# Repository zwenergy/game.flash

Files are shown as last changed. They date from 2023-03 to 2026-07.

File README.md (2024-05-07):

# game.flash
A Flash cartridge for the Tiger game.com handheld.

## Cartridge PCB
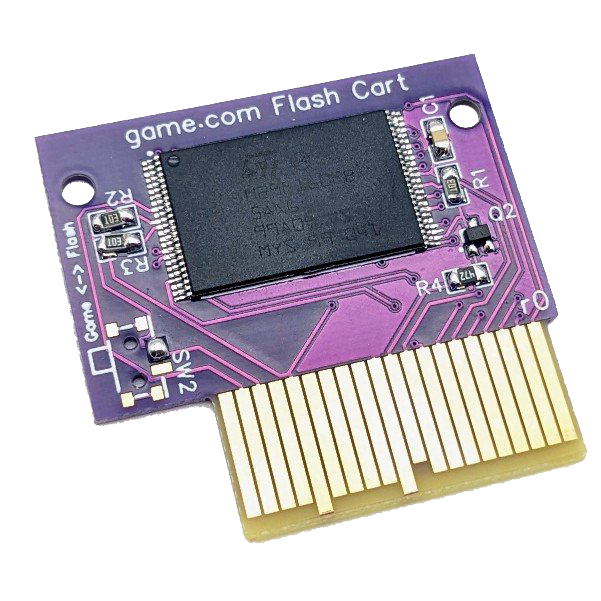
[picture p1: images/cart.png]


### BOM
| **Reference** | **Part** | **Link** |
|---|---|---|
|U1 | M29F160FB5AN6F2 2 MB Flash | [Digikey](https://www.digikey.de/en/products/detail/alliance-memory-inc/M29F160FB5AN6F2/12180105)|
|R1, R2, R3 | 10 kOhm Resistor (0805) | [LCSC](https://www.lcsc.com/product-detail/Chip-Resistor-Surface-Mount_UNI-ROYAL-Uniroyal-Elec-0805W8F1002T5E_C17414.html) |
|R4 | 4.7 kOhm Resistor (0805) | [LCSC](https://www.lcsc.com/product-detail/Chip-Resistor-Surface-Mount_UNI-ROYAL-Uniroyal-Elec-0805W8F4701T5E_C17673.html)
|C1 | 100 nF Capacitor (0805) | [LCSC](https://www.lcsc.com/product-detail/Multilayer-Ceramic-Capacitors-MLCC-SMD-SMT_YAGEO-CC0805KRX7R9BB104_C49678.html)
|Q2 | NPN Transistor (SOT-323-3) | [LCSC](https://www.lcsc.com/product-detail/Bipolar-Transistors-BJT_PANJIT-International-MMBT3904W_R1_00001_C142339.html)

The switch SW2 is not actually needed.
Instead, just connect the two pads as shown in the picture.

### Ordering Cartridge PCB
Order the cartridge PCB with ENIG/gold plated, "gold fingers" and chamfered edges.
Since, e.g., JLCPCB needs a minimum size for those features, you can find a panelized version which should fulfill those requirements.

A PCB thickness of 1.0 mm or 1.2 mm should work (1.0 mm works for me well, 1.2 mm is also successfully tested by somebody else).
Original game.com cartridge PCB seem to have a thickness of 1.0 mm or slightly above.
**When ordering thickness of 1.0 mm, you most likely have to slightly adjust the cart edge connector of the flasher PCB (e.g., carefully bend all pins slightly a bit more towards the center to put more pressure on the contacts), as otherwise the PCB is too loose and does not make properly contact (though works without problems for me on the game.com device).**

### Cartridge Case
An initial version of a 3D printable case is inside the case folder.
There are 2 "back part" versions.
One which has a "lip" like the original case (harder to print with an FDM printer), and one which has "flap" which more FDM printer-friendly.
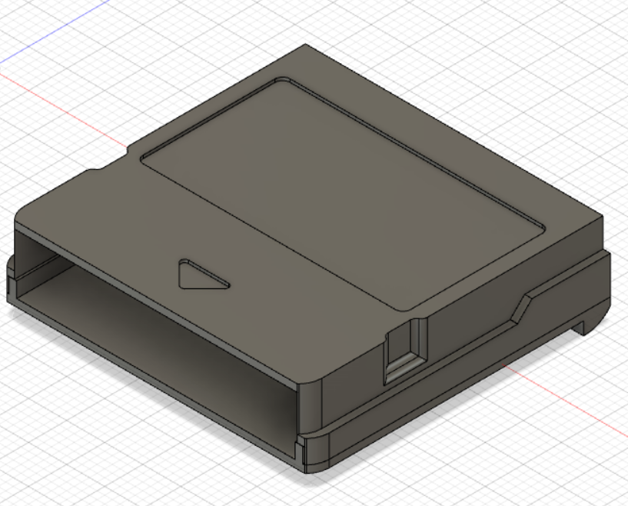
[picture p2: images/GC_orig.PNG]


A regular game.com cartridge case *should* work, although the cases seem to have quite some tolerance.
This means that some fit for me, some are too tight.

## Flasher PCB
The Flash chip on the cartridge can be re-flashed using an Arduino Mega and a "flasher shield".
**Make sure to insert the cartridge PCB's side with the Flash chip oriented towards the marked "chip-side" on the flasher PCB.**

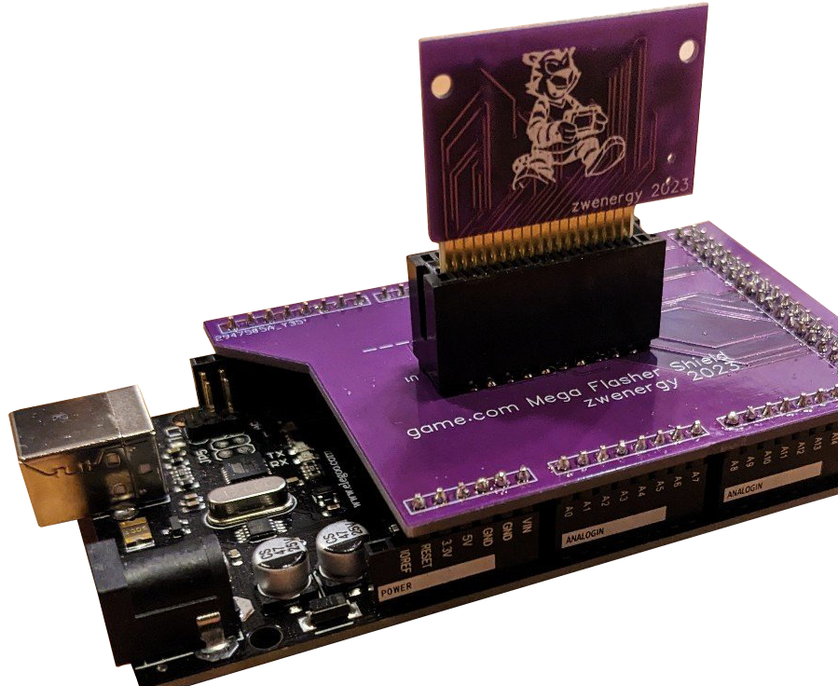
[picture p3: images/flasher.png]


### BOM
| **Reference** | **Part** | **Link** |
|---|---|---|
|U1 | RBB20DHHN Edge Connector | [Digikey](https://www.digikey.de/en/products/detail/sullins-connector-solutions/RBB20DHHN/927330)

## Flashing Software
Can be found under the code directory.
As a first step, program the Arduino Mega using the given .ino file and the Arduino IDE.
You don't need to redo this step anymore.

### Flashing script
A ROM file is flashed onto the cartridge by using the Python script ```flash.py```.
Make sure that you have Python installed. You also need the PySerial package.

The flash script can be used as follows:
```
flash.py ROMFILE COMPORT [MIRROR]
```

The parameter ```MIRROR``` is optional an can be either ```TRUE``` or ```FALSE``` (by default it is turned off).

Enabling ```MIRROR``` can be used to make "small" ROMs work (smaller than 2 MB). 
This is due to the that those smaller cartridges do not have the uppper address lines connected.
Hence the content "repeats" from the view of the handheld and it seems that it relies on this. 
As a "fix", I added the ```MIRROR``` option to the flashing script which repeats the content of the ROM along the 2 MB.
E.g., Lights Out only has the lower 15 address lines connected (from a total of 21 address lines). 
That means adress 0x0 will be the same as 0x8000, or 0x10000, etc.
My current guess is that the header is always checked at 0x40000, but just padding the header to that address is not enough.

Flashing a full 2 MB ROM currently takes around 15 minutes.

## Disclaimer
**Use the files and/or schematics to build your own board at your own risk**.
This board works fine for me, but it's a simple hobby project, so there is no liability for errors in the schematics and/or board files.
**Use at your own risk**.

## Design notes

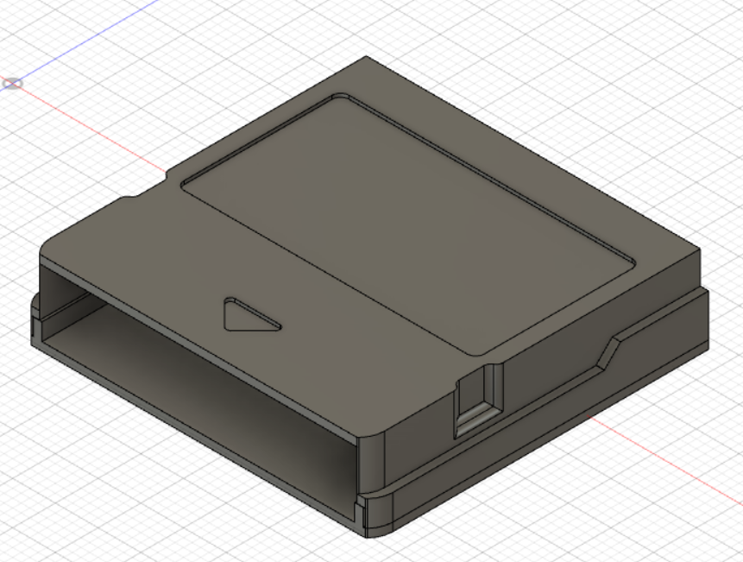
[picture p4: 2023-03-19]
images/GC_flap.PNG

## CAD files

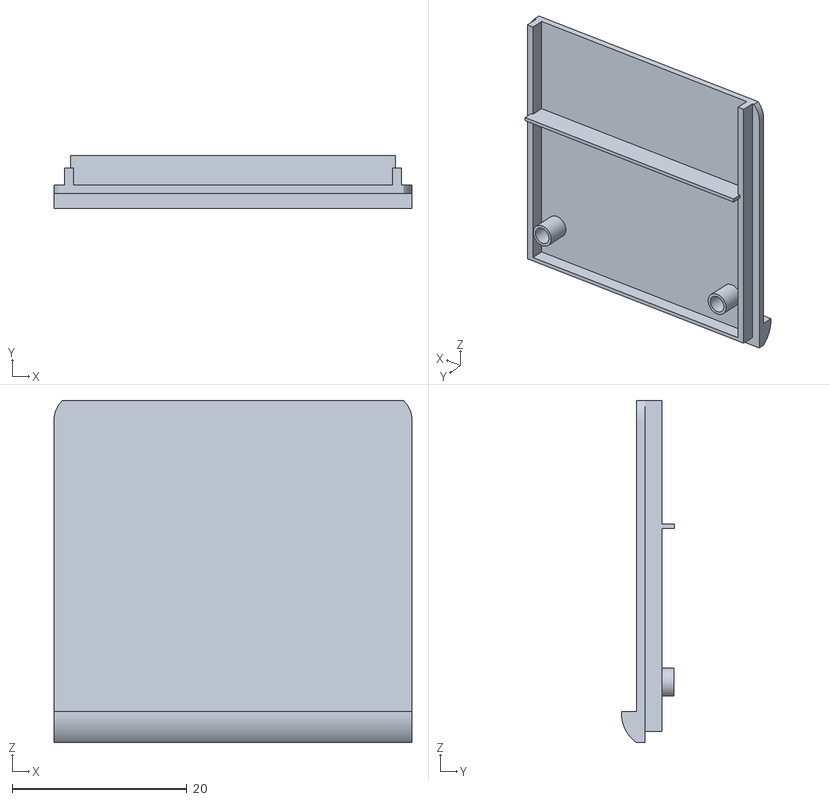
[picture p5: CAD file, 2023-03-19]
case/back_orig.stl
41.0 x 6.08 x 39.2

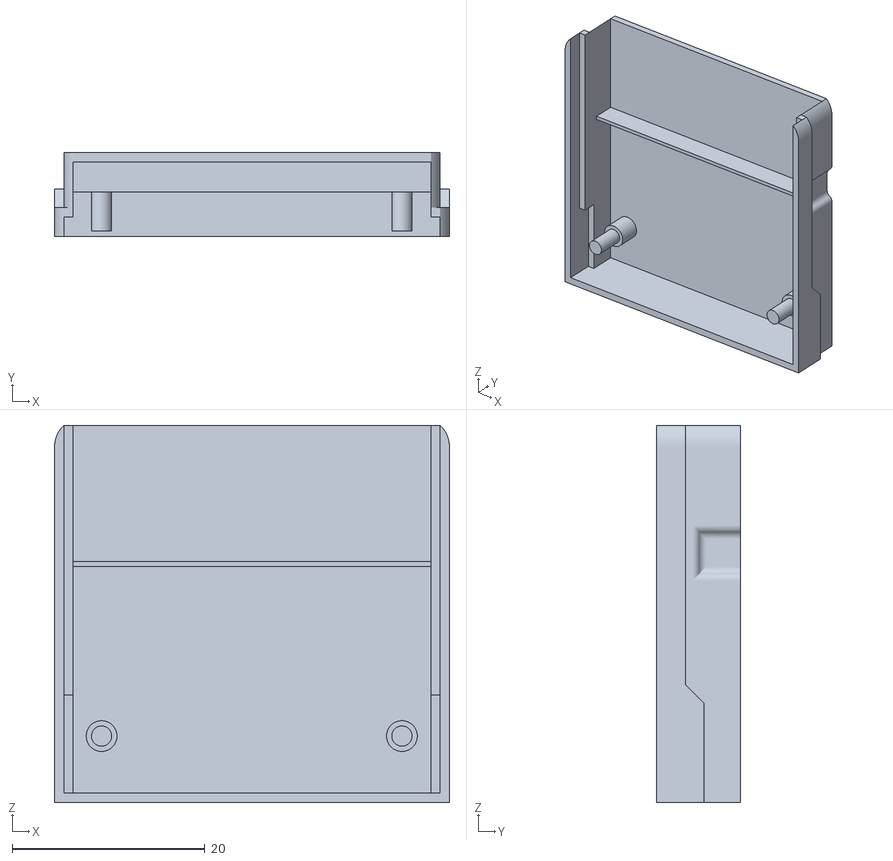
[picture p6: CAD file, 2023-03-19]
case/top.stl
41.0 x 8.73 x 39.2

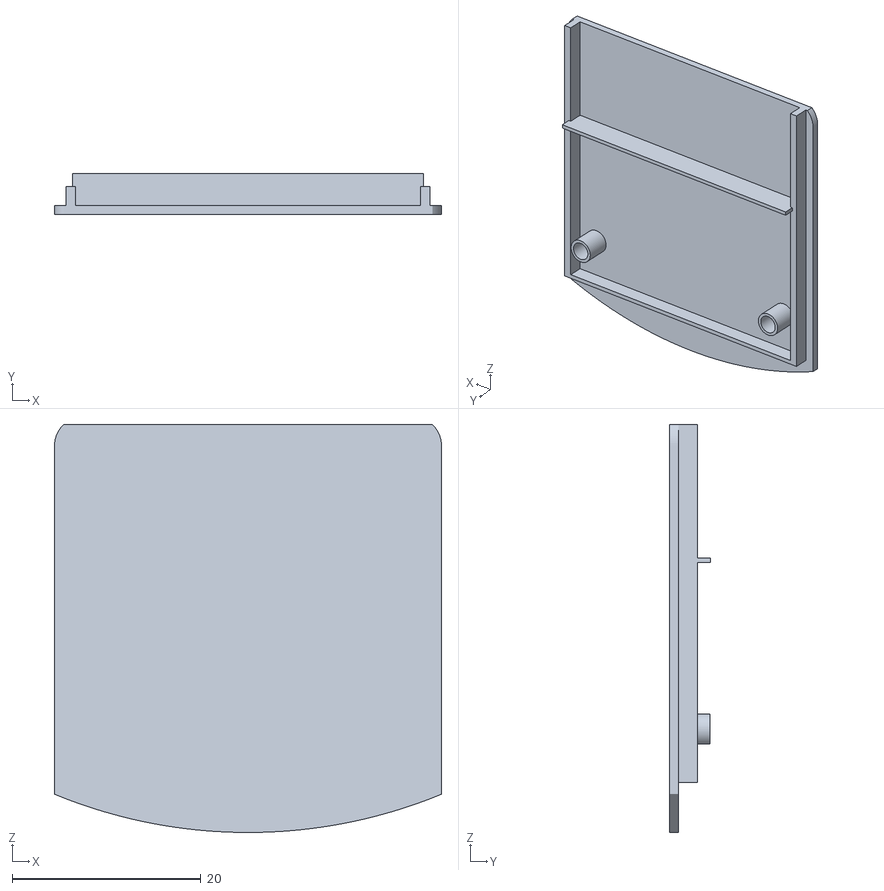
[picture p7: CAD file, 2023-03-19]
case/back_flap.stl
41.0 x 4.38 x 43.3

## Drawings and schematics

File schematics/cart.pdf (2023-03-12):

# A7 18 A6 19 A5 20 A4 21 A3 22 A2 23 A1 24 A0 25

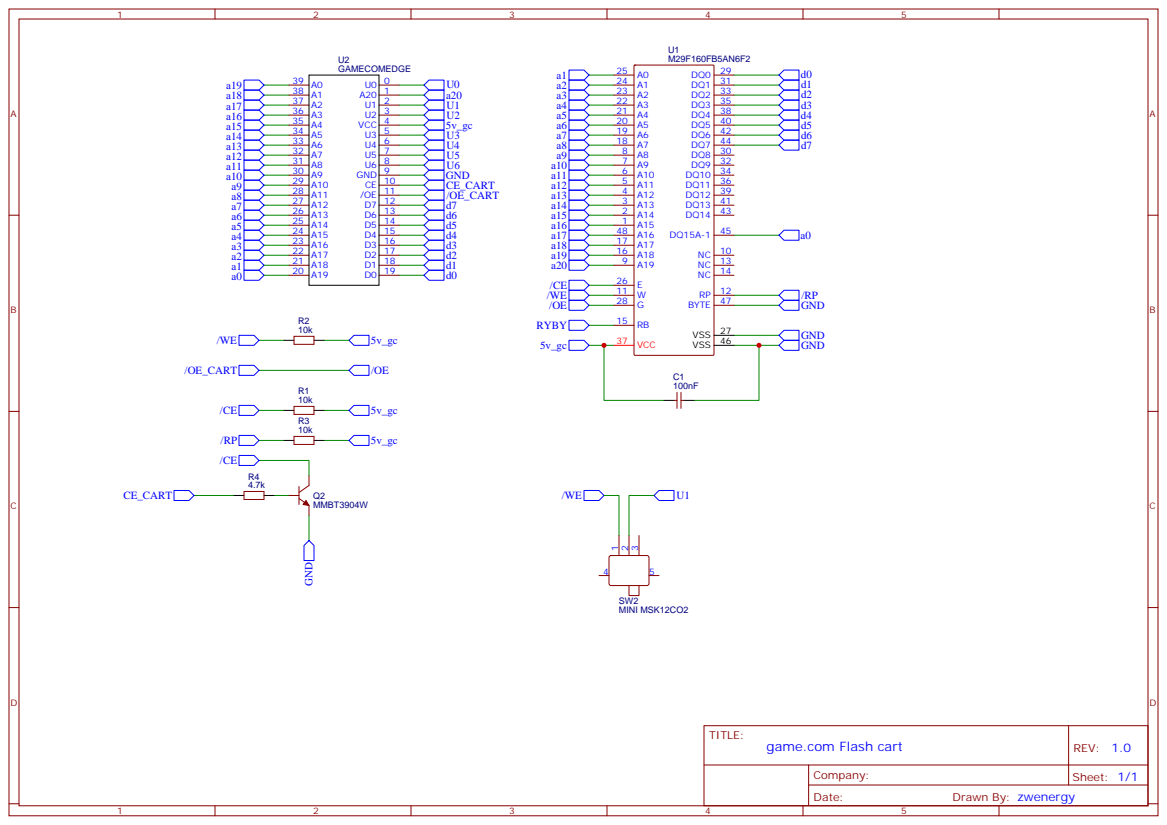
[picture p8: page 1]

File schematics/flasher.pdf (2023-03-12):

A

A

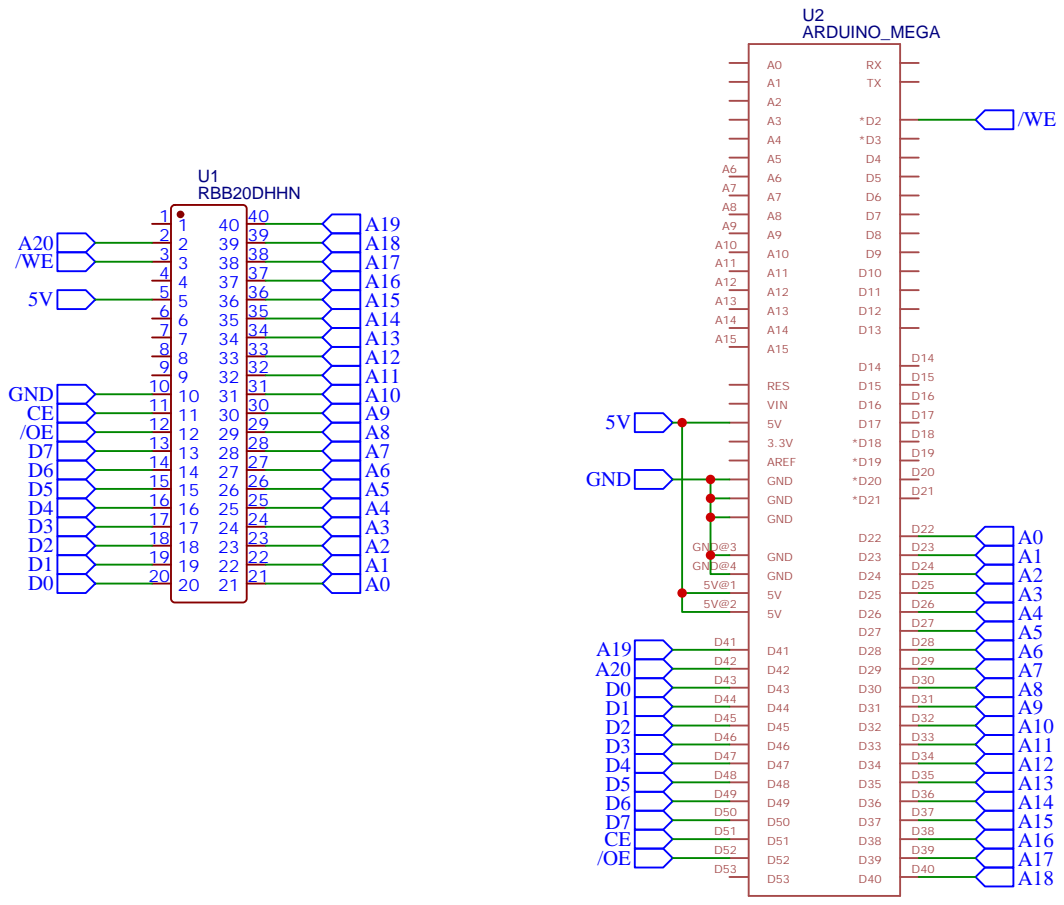
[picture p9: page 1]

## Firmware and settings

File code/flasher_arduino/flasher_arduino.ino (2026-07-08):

// Types (assuming you have these typedef'd elsewhere, standardizing for safety)
typedef uint32_t u32;
typedef uint8_t  u8;

// Pin definitions kept for reference, but physical manipulation 
// is now handled directly via hardware PORT registers.
#define A0 22
#define A1 23
#define A2 24
#define A3 25
#define A4 26
#define A5 27
#define A6 28
#define A7 29
#define A8 30
#define A9 31
#define A10 32
#define A11 33
#define A12 34
#define A13 35
#define A14 36
#define A15 37
#define A16 38
#define A17 39
#define A18 40
#define A19 41
#define A20 42

#define D0 43
#define D1 44
#define D2 45
#define D3 46
#define D4 47
#define D5 48
#define D6 49
#define D7 50

#define nWE 2  // PE4
#define nRP 3  // PE5
#define nRB 4  // PG5
#define CE 51  // PB2
#define nOE 52 // PB1

// Fast Control Pin Macros
#define nWE_HIGH (PORTE |= (1 << 4))
#define nWE_LOW  (PORTE &= ~(1 << 4))
#define nRP_HIGH (PORTE |= (1 << 5))
#define nRP_LOW  (PORTE &= ~(1 << 5))
#define CE_HIGH  (PORTB |= (1 << 2))
#define CE_LOW   (PORTB &= ~(1 << 2))
#define nOE_HIGH (PORTB |= (1 << 1))
#define nOE_LOW  (PORTB &= ~(1 << 1))

// Debug offset for dumping
#define OFFSET 262144
//#define OFFSET 0
#define MAXADDR 2097152

// Baud rate.
#define BAUD (250000)

// Wait time for chip erase. This is typically 25 seconds according to the data sheet, yet 
// at max. 120 seconds. If flashing is not done correctly, trying increasing this time value.
#define ERASE_WAIT_MS 30000

// NOP definitions for timing predictability
#define NOP1 asm volatile( "nop\n" )
#define NOP2 NOP1; NOP1
#define WAITSEQ NOP2

#define RXBYTES 32

void setDatPinsInput() {
  // D0-D6 map to PL6-PL0. D7 maps to PB3.
  DDRL &= 0b10000000; // Set PL0-PL6 to INPUT (leaves PL7 / A20 alone)
  DDRB &= ~(1 << 3);  // Set PB3 to INPUT
}

void setDatPinsOutput() {
  // D0-D6 map to PL6-PL0. D7 maps to PB3.
  DDRL |= 0b01111111; // Set PL0-PL6 to OUTPUT (leaves PL7 / A20 alone)
  DDRB |= (1 << 3);   // Set PB3 to OUTPUT
}

void setup() {
  Serial.begin( BAUD );
  
  // Set Address Pins to OUTPUT directly via Data Direction Registers (DDR)
  DDRA = 0xFF;         // A0-A7 (Pins 22-29) -> PA0-PA7
  DDRC = 0xFF;         // A8-A15 (Pins 30-37) -> PC7-PC0
  DDRD |= (1 << 7);    // A16 (Pin 38) -> PD7
  DDRG |= 0b00000111;  // A17-A19 (Pins 39-41) -> PG2, PG1, PG0
  DDRL |= (1 << 7);    // A20 (Pin 42) -> PL7

  // Data pins default to input
  setDatPinsInput();

  // Control pins direction setup
  DDRE |= (1 << 4);    // nWE (Pin 2, PE4) OUTPUT
  DDRE |= (1 << 5);    // nRP (Pin 3, PE5) OUTPUT
  DDRG &= ~(1 << 5);   // nRB (Pin 4, PG5) INPUT
  DDRB |= (1 << 2);    // CE (Pin 51, PB2) OUTPUT
  DDRB |= (1 << 1);    // nOE (Pin 52, PB1) OUTPUT

  // Initial Control states
  nWE_HIGH;
  nRP_HIGH;
  CE_LOW;
  nOE_HIGH;
}

void setAddrPins( u32 addr ) {  
  // A0 to A7 (Direct mapping to PORTA)
  PORTA = (u8)(addr & 0xFF);
  
  // A8 to A15 map to PC7 to PC0. We bit-reverse this using branchless math 
  // rather than a slow for-loop.
  u8 a8_15 = (u8)((addr >> 8) & 0xFF);
  a8_15 = (a8_15 & 0xF0) >> 4 | (a8_15 & 0x0F) << 4;
  a8_15 = (a8_15 & 0xCC) >> 2 | (a8_15 & 0x33) << 2;
  a8_15 = (a8_15 & 0xAA) >> 1 | (a8_15 & 0x55) << 1;
  PORTC = a8_15;
  
  // A16 (PD7)
  if ( addr & (1ul << 16) ) {
    PORTD |= (1 << 7); 
  } else {
    PORTD &= ~(1 << 7);
  }
  
  // A17 (PG2), A18 (PG1), A19 (PG0). Mask and shift in one go.
  u8 pg_mask = (((addr >> 17) & 1) << 2) | 
               (((addr >> 18) & 1) << 1) | 
               (((addr >> 19) & 1));
  PORTG = (PORTG & 0xF8) | pg_mask;
  
  // A20 (PL7)
  if ( addr & (1ul << 20) ) { 
    PORTL |= (1 << 7);
  } else {
    PORTL &= ~(1 << 7);
  }
}

void setDataOutput( unsigned dat ) {
  // D0-D6 go to PL6-PL0 reversed. Branchless shift mapping.
  u8 l_out = ((dat & 0x01) << 6) | ((dat & 0x02) << 4) | ((dat & 0x04) << 2) |
             ((dat & 0x08)     ) | ((dat & 0x10) >> 2) | ((dat & 0x20) >> 4) |
             ((dat & 0x40) >> 6);
             
  PORTL = (PORTL & 0x80) | l_out; // Apply leaving PL7 (A20) intact
  
  // D7 goes to PB3
  if (dat & 0x80) PORTB |= (1 << 3);
  else PORTB &= ~(1 << 3);
}

// Dump game.
void doDump() {
  Serial.println( "DoDump" );
  setDatPinsInput();
  
  // Activate chip.
  CE_HIGH;
  nOE_LOW;
  nWE_HIGH;
  nRP_HIGH;
  
  // Wait.
  delayMicroseconds( 10 );
  Serial.println( "waited" );

  // Start dump.
  for ( u32 i = OFFSET; i < MAXADDR + OFFSET; ++i ) {
    setAddrPins( i );
    WAITSEQ;
    
    // Read data pins directly from PIN hardware registers.
    // Reversing PL6-PL0 back into bits 0-6, and placing PB3 into bit 7.
    u8 l = PINL;
    char dat = ((l & 0x40) >> 6) | ((l & 0x20) >> 4) | ((l & 0x10) >> 2) |
               ((l & 0x08)     ) | ((l & 0x04) << 2) | ((l & 0x02) << 4) |
               ((l & 0x01) << 6) | ((PINB & 0x08) << 4);

    // Send it.
    Serial.write( dat );
  }

  // Turn off again.
  CE_LOW;
  nOE_HIGH;
}

void writeToAddress( u32 addr, u8 data ) {
  // Set the address.
  setAddrPins( addr );
  // Set the data.
  setDataOutput( data );

  // Activate chip.
  CE_HIGH;
  nWE_LOW;

  WAITSEQ;

  // Deactivate.
  nWE_HIGH;
  CE_LOW;
}

void unlockBypass() {
  CE_HIGH;
  nOE_HIGH;
  nWE_HIGH;

  setDatPinsOutput();
  
  writeToAddress( 0xAAA, 0xAA );
  WAITSEQ;

  writeToAddress( 0x555, 0x55 );
  WAITSEQ;

  writeToAddress( 0xAAA, 0x20 );
  WAITSEQ;

  setDatPinsInput();
  nOE_HIGH;
  nWE_HIGH;
}

void unlockBypassReset() {
  CE_HIGH;
  nOE_HIGH;
  nWE_HIGH;

  setDatPinsOutput();
  
  writeToAddress( 0x111, 0x90 );
  WAITSEQ;

  writeToAddress( 0x111, 0x00 );
  WAITSEQ;

  setDatPinsInput();
  nOE_HIGH;
  nWE_HIGH;
}

void doBypassProgram( u32 addr, u8 data ) {
  CE_HIGH;
  nOE_HIGH;
  nWE_HIGH;

  setDatPinsOutput();
  
  writeToAddress( 0x111, 0xA0 );
  WAITSEQ;

  writeToAddress( addr, data );
  WAITSEQ;

  setDatPinsInput();
  nOE_HIGH;
  nWE_HIGH;
}

void doChipErase() {
  CE_HIGH;
  nOE_HIGH;
  nWE_HIGH;
  
  setDatPinsOutput();
  
  writeToAddress( 0xAAA, 0xAA );
  WAITSEQ;
  writeToAddress( 0x555, 0x55 );
  WAITSEQ;
  writeToAddress( 0xAAA, 0x80 );
  WAITSEQ;
  writeToAddress( 0xAAA, 0xAA );
  WAITSEQ;
  writeToAddress( 0x555, 0x55 );
  WAITSEQ;
  writeToAddress( 0xAAA, 0x10 );

  delay( ERASE_WAIT_MS );

  setDatPinsInput();
  nOE_HIGH;
  nWE_HIGH;
}

void doProgram( u32 addr, u8 data ) {
  writeToAddress( 0xAAA, 0xAA );
  WAITSEQ;
  writeToAddress( 0x555, 0x55 );
  WAITSEQ;
  writeToAddress( 0xAAA, 0xA0 );
  WAITSEQ;
  
  writeToAddress( addr, data );
  WAITSEQ;
}

void doFlash() {
  nRP_HIGH;

  CE_HIGH;
  nOE_HIGH;
  nWE_HIGH;

  setDatPinsOutput();

  u32 nrBytes = 0;

  while ( nrBytes < MAXADDR ) {
    if ( Serial.available() >= RXBYTES ) {
      for ( int i = 0; i < RXBYTES; ++i ) {
        char b = Serial.read();
        doProgram( nrBytes, b );
        ++nrBytes;
      }
      char conf = 1;
      Serial.write( conf );
      Serial.flush();
    }
  }

  CE_LOW;
  nOE_HIGH;
  nWE_HIGH;
  
  setDatPinsInput();
}

void doFlashBypass() {
  CE_HIGH;
  nOE_HIGH;
  nWE_HIGH;

  setDatPinsOutput();

  u32 nrBytes = 0;
  unlockBypass();

  while ( nrBytes < MAXADDR ) {
    if ( Serial.available() >= RXBYTES ) {
      for ( int i = 0; i < RXBYTES; ++i ) {
        char b = Serial.read();
        doBypassProgram( nrBytes, b );
        ++nrBytes;
      }
      char conf = 1;
      Serial.write( conf );
      Serial.flush();
    }
  }

  CE_LOW;
  nOE_HIGH;
  nWE_HIGH;
  
  setDatPinsInput();
  unlockBypassReset();
}

void loop() {
  if ( Serial.available() ) {
    char rx = Serial.read();
    if ( rx == 42 ) {
      doDump();
    } else if ( rx == 82 ) {
      doFlashBypass();
    } else if ( rx == 14 ) {
      unlockBypassReset();
    } else if ( rx == 123 ) {
      doChipErase();
      Serial.write( 42 );
    }
  }
}

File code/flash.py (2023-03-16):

#!/usr/bin/env python3

# A script to flash the game.flash cartridge.
# Author: zwenergy

import serial
import time
import math
import sys

# Some definitions up first.
BYTES = 32
BAUD = 250000
CMDERASE = 123
CMDFLASH = 82
CMDUNLOCKBYPASSRESET = 14
INCRMOD = 1024

# Get the command line.
if ( not( len( sys.argv ) == 3 or len( sys.argv ) == 4 ) ):
  print( "Wrong usage. Use of script:" )
  print( "flash.py ROMFILE COMPORT [MIRROR]" )
  print( "\nWhere [MIRROR] is optional and can be either TRUE or FALSE. By default it is turned off." )
  exit( 1 )


romfile = sys.argv[ 1 ]
comport = sys.argv[ 2 ]
mirror = False

if ( len( sys.argv ) == 4 ) :
  tmp = sys.argv[ 3 ]
  if ( tmp.lower() == "true" ):
    mirror = True
  elif ( tmp.lower() == "false" ):
    mirror = False
  else:
    print( "Wrong usage. Optional command MIRROR can be either TRUE or FALSE." )
    print( "Given argument: " + tmp )
    exit( 1 )

ser = serial.Serial( comport, BAUD,
  bytesize=serial.EIGHTBITS,
  parity=serial.PARITY_NONE,
  stopbits=serial.STOPBITS_ONE,
  timeout=0,
  xonxoff=0,
  rtscts=0 )

time.sleep( 1 )

print( "Opened COM port." )

# Reset the arduino by toggling the DTR line.
print( "Resetting Arduino." )
ser.dtr = False;
time.sleep( 1 );
ser.flushInput()
ser.dtr = True;
time.sleep( 1 );

# Send unlock bypass reset signal (in case flashing was interrupted before)
vals = [ CMDUNLOCKBYPASSRESET ]
ser.write( bytearray( vals ) )
time.sleep( 0.5 )

print( "Start erasing chip contents." )

# Send erase command.
vals = [ CMDERASE ]
ser.write( bytearray( vals ) )
time.sleep( 1 )

# Wait until done.
while( not ser.in_waiting ):
    # Dummy.
    a = 0

# Will send exactly one byte.
r = ser.read()

print( "Chip erased." )

f = open( romfile, "rb" )
rom = f.read()

i = 0
romLen = len( rom )
maxAddr = len( rom )

if ( mirror ):
  maxAddr = 2097152
  if ( ( romLen & ( romLen - 1 ) == 0) and romLen != 0 ):
    print( "Mirror on and ROM is power 2." )
  else:
    print( "Mirror on and ROM is NOT power 2, verify if this is correct." )

print( "Starting to flash." )

# Send flash mode command.
vals = [ CMDFLASH ]
ser.write( bytearray( vals ) )
time.sleep( 1 )

while ( i < maxAddr ):
  tmp = []
  for jj in range( BYTES ):
    if ( i < maxAddr ):
      tmp.append( rom[ i % romLen ] )
      i += 1
    else:
      break
      
  ser.write( bytearray( tmp ) )
  
  if ( i % INCRMOD == 0 ):
    print( "Wrote " + str( i ) + " of " + str( maxAddr ) )
  
  while( not ser.in_waiting ):
    # Dummy
    a = 0

  r = ser.read()

print( "Done flashing." )

f.close()
ser.close()

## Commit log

2023-03-12 Added board files.
2023-03-19 Added case and images.
    [back_flap.stl, back_orig.stl, top.stl]
2026-07-08 Re-wrote parts of the Arduino code for faster flashing.
